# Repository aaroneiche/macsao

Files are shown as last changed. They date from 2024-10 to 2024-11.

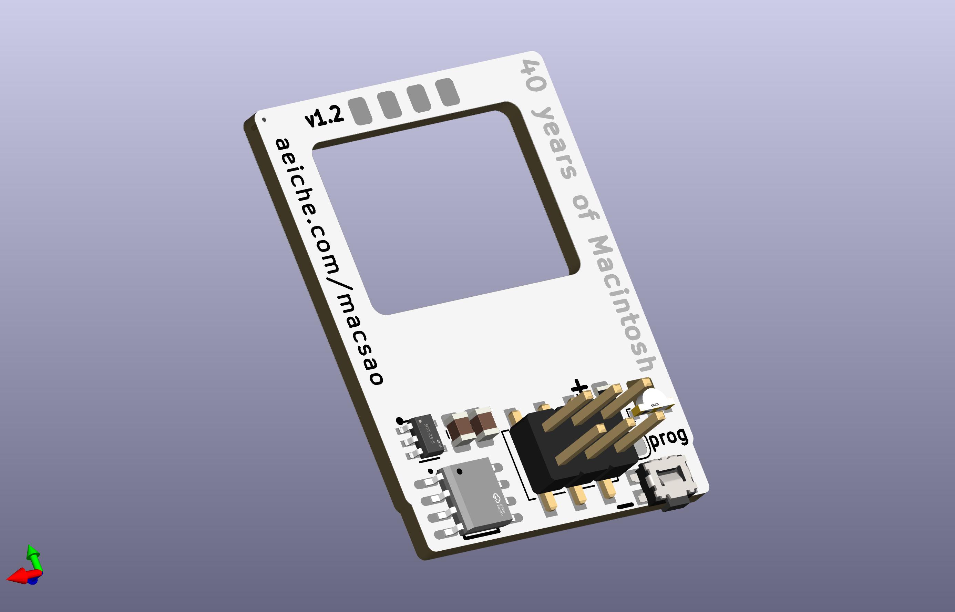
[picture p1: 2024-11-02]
other/MacSAO3D.jpg

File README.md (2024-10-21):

# Mac SAO 

The Mac SAO is a simple add-on I've built heading into Hackaday Supercon 2024. It is a celebration of the original Macintosh, which debuted 40 years ago in 1984. 

In the spirit of Open source and good faith hardware hacking, all of the code here is open to use. If you do so, I would love to know.

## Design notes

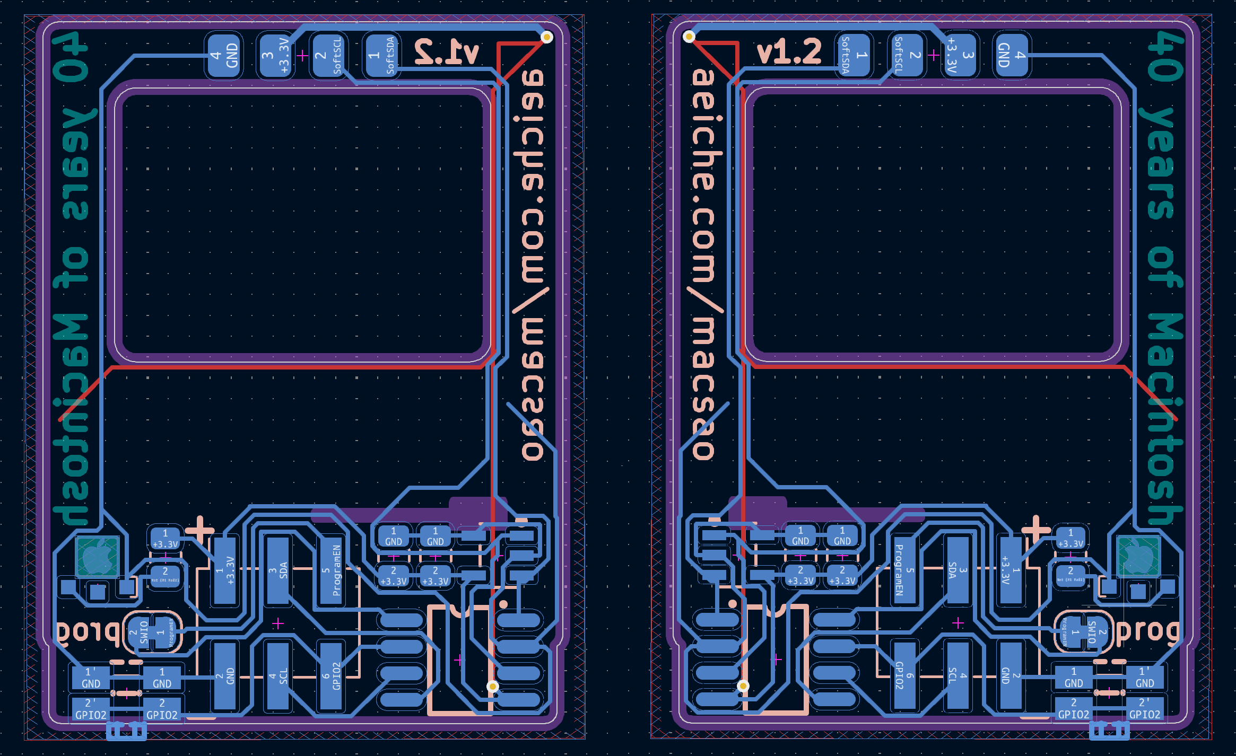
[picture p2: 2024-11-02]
other/frontAndBack.png

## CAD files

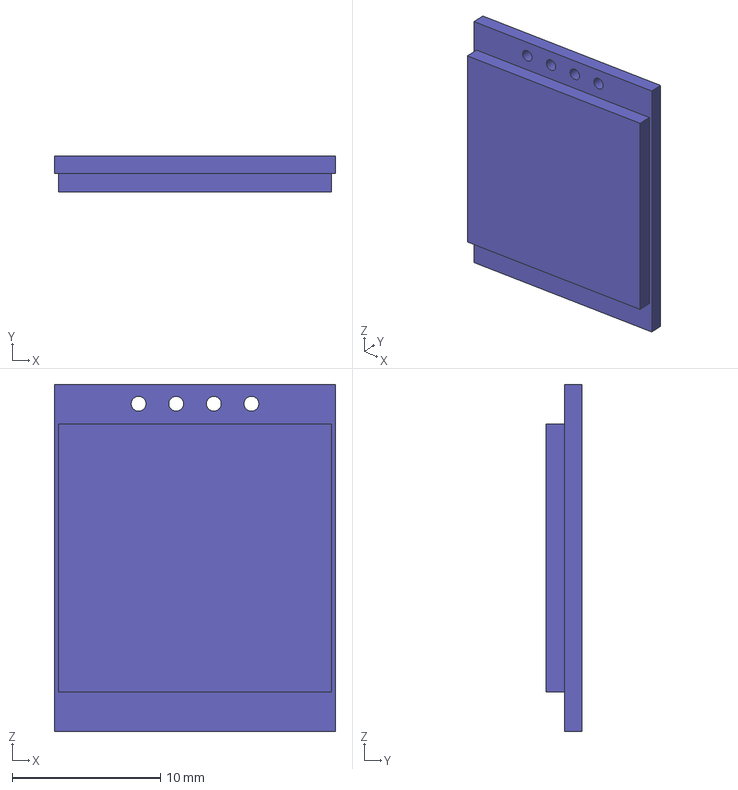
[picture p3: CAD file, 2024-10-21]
hardware/oledModule.step
19.0 x 2.45 x 23.4 mm

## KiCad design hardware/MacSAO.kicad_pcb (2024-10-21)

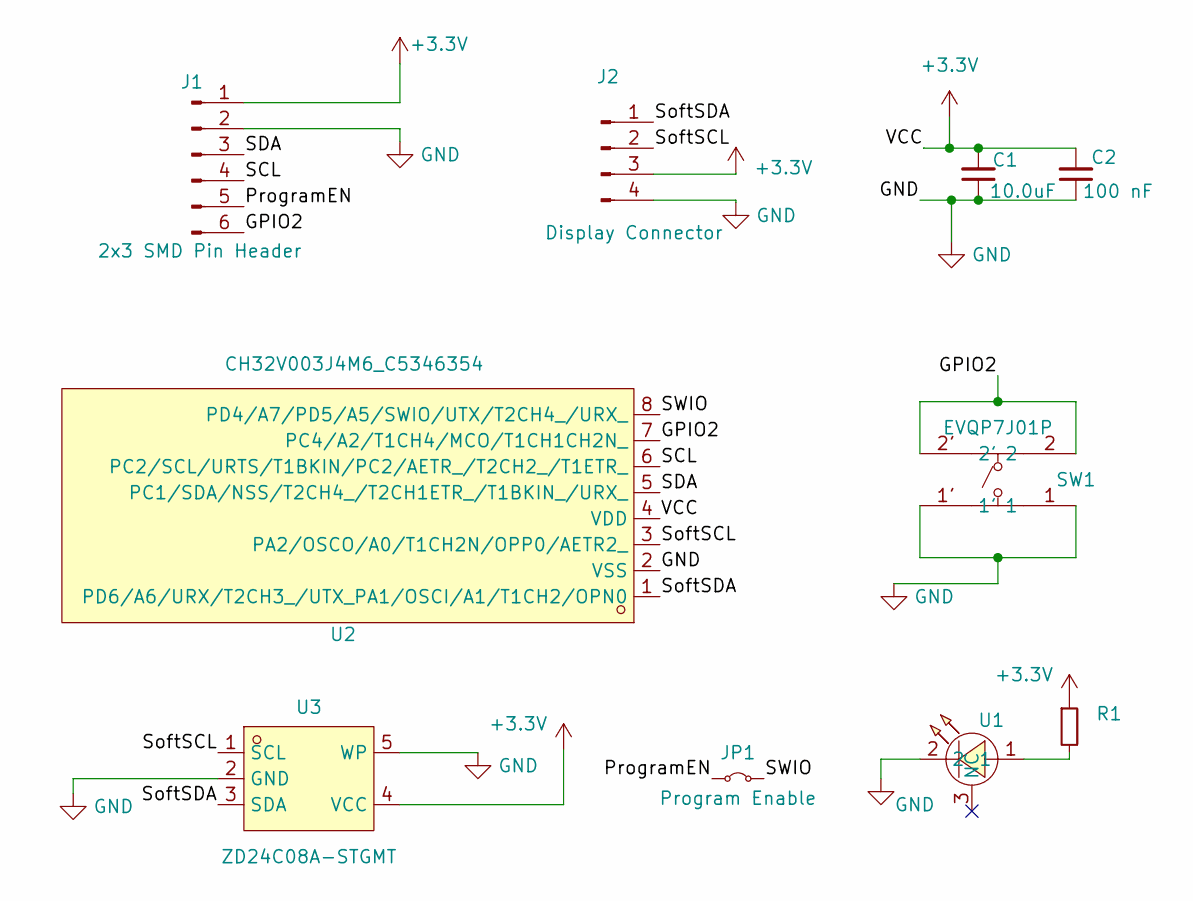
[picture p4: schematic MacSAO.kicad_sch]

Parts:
C1: 10.0uF; C_0805_2012Metric
C2: 100 nF; C_0805_2012Metric
J1: 2x3 SMD Pin Header; PinHeader_2x03_P2.54mm_Vertical_SMD
J2: Display Connector; 1x04_SMD_OLED
JP1: Program Enable; SolderJumper-2_P1.3mm_Bridged_RoundedPad1.0x1.5mm
R1: 1.8Kohm; R_0805_2012Metric
SW1: EVQP7J01P; SW-SMD_EVQP7J01P; LCSC Part C2828254
U1: A-SP110GHC-C01-2C; LED-SMD_L3.0-W1.5_MHS110WDT-C1; LCSC Part C5151480
U2: CH32V003J4M6_C5346354; SOP-8_L4.9-W3.8-P1.27-LS6.0-BL; LCSC Part C5346354
U3: ZD24C08A-STGMT; SOT-23-5_L3.0-W1.7-P0.95-LS2.8-BL; LCSC Part C2896640

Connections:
+3.3V: C1.2, C2.2, J1.1, J2.3, R1.1, U2.4 (VDD), U3.4 (VCC)
/GPIO2: J1.6, SW1.2, SW1.2', U2.7 (PC4/A2/T1CH4/MCO/T1CH1CH2N_)
/ProgramEN: J1.5, JP1.1 (A)
/SCL: J1.4, U2.6 (PC2/SCL/URTS/T1BKIN/PC2/AETR_/T2CH2_/T1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)
/SDA: J1.3, U2.5 (PC1/SDA/NSS/T2CH4_/T2CH1ETR_/T1BKIN_/UR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)
/SWIO: JP1.2 (B), U2.8 (PD4/A7/PD5/A5/SWIO/UTX/T2CH4_/URX_)
/SoftSCL: J2.2, U2.3 (PA2/OSCO/A0/T1CH2N/OPP0/AETR2_), U3.1 (SCL)
/SoftSDA: J2.1, U2.1 (PD6/A6/URX/T2CH3_/UTX_PA1/OSCI/A1/T1CH2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), U3.3 (SDA)
GND: C1.1, C2.1, J1.2, J2.4, SW1.1, SW1.1', U1.2, U2.2 (VSS), U3.2 (GND), U3.5 (WP)
unnamed: R1.2, U1.1

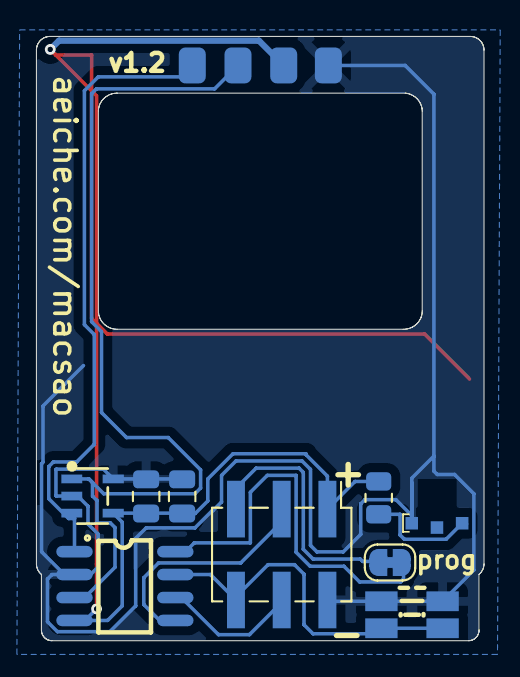
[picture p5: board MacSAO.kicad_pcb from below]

Board: 2 copper layers, 24.9 x 33.6 mm, 10 parts (10 on the bottom side), 10 nets.

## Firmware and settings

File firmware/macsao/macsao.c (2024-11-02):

/*
 * MacSAO Firmware Aaron Eiche 2024
 * 
 * Started from E. Brombaugh's OLED Demo, 
 * Utilizes ADBeta's Software I2C Library
 */

// what type of OLED - uncomment just one
#define SSD1306_64X48
// #define SSD1306_64X32
// #define SSD1306_128X32
// #define SSD1306_128X64

#ifndef _FUNCONFIG_H
#define _FUNCONFIG_H

// Though this should be on by default we can extra force it on.
#define FUNCONF_USE_DEBUGPRINTF 1
#define FUNCONF_DEBUGPRINTF_TIMEOUT (1 << 31) // Wait for a very very long time.

#define CH32V003 1

#endif

#include "ch32v003fun.h"
#include <stdio.h>
#include "ssd1306.h"
#include <string.h>

// #include "bomb.h"
#include "../extralibs/ch32v003_GPIO_branchless.h"
#include "i2c_slave.h"
#include "lib_swi2c.c"
#include "ssd1306_i2c.h"

#include "decoder.c"

// State: Either in settings mode or "Mac" animation playback.
#define MAC 0
#define SETTINGS 1

#define ANIMATE 0
#define LIVEDRIVE 1
#define SETTINGS 2



uint8_t mode = ANIMATE;
uint8_t lastMode = ANIMATE;
bool hasDrawn = false;

volatile uint32_t overflowCount = 0;

uint8_t buttonLastState = 0;
int start = 0;
int stop = -1;
bool counting = false;
bool buttonShortPress = false;

//Where i2c input goes after being received.
volatile uint8_t i2c_registers[32] = {};

//Where EEPROM data is put to make available externally.
volatile uint8_t eepData[64]; // max data to read in.

const uint8_t defaultStack[] = {
// 1,2,5,5,5,35,24,1,254,16,34,38,22,3,4,255,1,2,5,5,5,10,30,1,254,16,10,18,255,255};
1,1,254,16,58,8,255,1,3,5,5,8,35,24,2,254,22,4,6,16,58,43,16,8,11,255,255};

//Default display stack
volatile uint8_t displayStack[255] = {
	/*
	//Writes "Welcome to Supercon"

	3, 255, 16, 48, 40, 3, 255, 16, 9, 2,
	3, 255,
	20, 4, 20, 87, 101, 108, 99, 111, 109, 101, 32, 116, 111,
	115, 117, 112, 101, 114, 99, 111, 110, 254,
	3, 255,
	19, 4, 20, 87, 101, 108, 99, 111, 109, 101, 32, 116, 111,
	115, 117, 112, 101, 114, 99, 111, 110, 254,
	18, 10, 255
	 */
};

// This stack displays the settings menu. 
// The 3rd arg (10) is the selected value of the settings, 
// its updated when preferences are loaded.
volatile uint8_t settingsStack[32] = {
	1, 1, 48, 10, 254, 254, 254, 254 //, 16, 38, 40, 255, 255
};

volatile uint8_t preferences[16];

/* 
These variables keep track of the step in the sequence we're on, 
as well as the item in the sequence we're currently drawing.
 */
uint8_t * stackPtr = displayStack; // 
// uint8_t * stepPtr = displayStack; // each step in the display stack.


uint8_t * bgStartPtr = displayStack;
uint8_t * actionStartPtr;

// Keeps track of persistant info:
// Mouse X,Y, and animation step complete(0:1), wait count
uint8_t store[] = {5, 5, 0, 0};

uint16_t r_addr;
uint8_t len;

uint8_t	ssd1306_soft_init(void);

// volatile uint8_t state = MAC;
// volatile uint8_t state = SETTINGS;
bool drawn = false;

void onWrite(uint8_t reg, uint8_t length) {
	for(int c = 0; c < length; c++) {
		printf("%u: %u\n", c, i2c_registers[c]);
	}

	//Reset the state of the i2c lines, in case anything else is happening.
	swi2c_init(&device);

	switch (i2c_registers[0])
	{
		case 1: {
		//write to display data.
		
		//Clear the store data in case the new command is using it.
		store[3] = 0;

		// Get the address offset to write
		uint8_t offset = i2c_registers[1];

		for (int i = 2; i <= length; i++)
		{
			displayStack[offset + i - 2] = i2c_registers[i];
		};

		// displayStack[length-1] = 0xFF; // A final byte at the end of last animation
		
		stackPtr = displayStack;
		actionStartPtr = displayStack;
		bgStartPtr = displayStack;

		if(mode == LIVEDRIVE) {
			hasDrawn = false;
		}

		break;
		}
		case 2: 
		//write to stored memory

		// 16bit address. Here to auto-overflow. 
		uint16_t addr = (i2c_registers[1] << 8) | i2c_registers[2];
		// printf("address: %4x\n", addr);
		// Get distance to end of page.

		uint8_t bytesForPage = 32 - (addr % 32); // How far to end of page.

		uint8_t *sptr = i2c_registers + 3; //A pointer to the first byte we're gonna send.
		int8_t dataLen = length - 3; // Length of the data to store.

		// printf("data length: %u\n", dataLen);
		// printf("byte value of array: %u\n", sptr);
		while (dataLen > 0) // While there are bytes to write
		{
			// printf("another loop: %u\n", dataLen);
			// printf("addr: %u, bytesForPage %u, datalength %u\n", addr, bytesForPage, dataLen);

			if (dataLen > bytesForPage) // We have more bytes than can write in this page.
			{

				// printf("sending %u bytes to %4x\n",addr, dataLen);
				//send bytes at pointer, for bytesForPage length
				swi2c_master_transmit_eeprom(&eeprom, addr, sptr, dataLen);
				
				//reduce the number of bytes to write.
				dataLen -= bytesForPage;
				
				//increment the address pointer
				sptr +=  bytesForPage; // Array pointer
				addr += bytesForPage; // address value.

				// update bytesForPage to the next length of bytes to send.
				bytesForPage = 32 - (addr % 32);
			}
			else // We can write these bytes just to this page.
			{
				// printf("one shot: sending %u bytes to %4x\n", dataLen, addr);
				swi2c_master_transmit_eeprom(&eeprom, addr, sptr, dataLen);
				dataLen -= bytesForPage; // subtract remaining bytes.
			}
		}

		break;

		case 3: //Read Data either from display stack (FFFF) or FROM EEPROM (0000-2000)
			
			r_addr = (i2c_registers[1] << 8) | i2c_registers[2]; //16-bit address
			len = i2c_registers[3];
			
			if(r_addr == 0xFFFF) { 
				// FFFF is not a valid EEPROM address (this is only 64kbits)
				//Read display stack in, rather than 
				for(int i = 0; i < len; i++){
					eepData[i] = displayStack[i];
				}
			}else{
				swi2c_master_receive_eeprom(&eeprom, r_addr, eepData, len);
			}
						
			
			for (int i = 0; i < len; i++)
			{
				// printf("%u: %u\n", i, eepData[i]);
				i2c_registers[i] = eepData[i];
				// memcpy(i2c_registers, eepData, len); //copy the data over to i2cr
			}
			// memcpy(i2c_registers, eepData, len);
			// for (int r = 0; r < len; r++)
			// {
			// 	printf("reg %u: %u\n",r,i2c_registers[r]);
			// }
		break;
		case 4:
			// Load a sequence from EEPROM into displayStack
			// 4 Args: Address Hi, Address Low, Number of Bytes, offset on displayStack

			uint16_t r_addr = (i2c_registers[1] << 8) | i2c_registers[2]; // 16-bit address
			len = i2c_registers[3];						// Number of bytes to read

			// Where to place the new bytes in the display stack
			// useful if you want to add to existing stack.
			uint8_t stackOffset = i2c_registers[4];		
			swi2c_master_receive_eeprom(&eeprom, r_addr, eepData, len);

			// write eepData vals into displayStack
			for(int i = 0; i < len; i++) {
				displayStack[stackOffset + i] = eepData[i]; 
			}
			
			displayStack[stackOffset + len] = 255; // Extra 255 at end of new data indicates end of Sequence.

			// reset display stack
			stackPtr = displayStack;
			actionStartPtr = displayStack;
			bgStartPtr = displayStack;
		break;
		
		case 5: 
			//Set one of the variables in the Mac.
			switch (i2c_registers[1]) {
				case 1: // Animate(0) or LiveDrive(1)
					lastMode = mode;
					mode = i2c_registers[2];
					// printf("setting mode to %u", mode);
				break;
				case 2: // Mouse X,Y
					store[0] = i2c_registers[2];
					store[1] = i2c_registers[3];
					// printf("set mouse X,Y to %u,%u", store[0], store[1]);
				break;
			}

			stackPtr = displayStack;
			actionStartPtr = displayStack;
			bgStartPtr = displayStack;

			if(mode == LIVEDRIVE) {
				hasDrawn = false; // Trigger an update.
			}
			break;
		case 6:
			//Read variable value;
			switch (i2c_registers[1])
			{
			case 1: // Animate(0) or LiveDrive(1)
				i2c_registers[0] = mode;
				break;
			case 2: // Mouse X,Y
				i2c_registers[0] = store[0];
				i2c_registers[1] = store[1];
				break;
			}
		}
	printf("command finished.\n");

}

void onRead(uint8_t reg) {
	// read data out of eepData
	// SetupI2CSlave
	printf("Read %u at ...\n",i2c_registers[reg], reg);
}


/* 
	Explicitly sets the i2c address of the MacSAO
*/
void setI2CAddress(uint8_t addressVal){
	if (swi2c_start(&eeprom) == I2C_OK)
	{
		swi2c_master_tx_byte(&eeprom, eeprom.address);		  // Transmit Address w/write bit;
		swi2c_master_tx_byte(&eeprom, 0); // Address High Byte
		swi2c_master_tx_byte(&eeprom, 0);		  // Address Low Byte
		swi2c_master_tx_byte(&eeprom, addressVal); // Address Low Byte
		swi2c_stop(&eeprom);
	}
} 

void readData(uint8_t addrH, uint8_t addrL, uint8_t data[], uint8_t length)
{
	if (swi2c_start(&eeprom) == I2C_OK)
	{
		swi2c_master_tx_byte(&eeprom, eeprom.address); // Transmit Address w/write bit;
		swi2c_master_tx_byte(&eeprom, addrH);		   // Page Address High Byte
		swi2c_master_tx_byte(&eeprom, addrL);		   // Page Address Low Byte
		// swi2c_stop(&eeprom);
	}

	if (swi2c_start(&eeprom) == I2C_OK)
	{
		swi2c_master_tx_byte(&eeprom, eeprom.address | 1); // Transmit Address w/read bit;
		for (int i = 0; i < length; i++)
		{
			
			data[i] = swi2c_master_rx_byte(&eeprom, I2C_ACK); //Read bytes into data.
			// printf("read %u %u\n",i, data[i]);
		}
		swi2c_master_rx_byte(&eeprom, I2C_NACK); //End Sequential Read.
		swi2c_stop(&eeprom);
	}
}

void writeData(uint8_t addrH, uint8_t addrL,  uint8_t data[], uint8_t length ) {
	printf("writing data\n");
	if (swi2c_start(&eeprom) == I2C_OK)
	{
		// printf("i2c ok: ");
		swi2c_master_tx_byte(&eeprom, eeprom.address); 	// Transmit Address w/write bit;
		swi2c_master_tx_byte(&eeprom, addrH); 			// Address High Byte
		swi2c_master_tx_byte(&eeprom, addrL);		  	// Address Low Byte
		for(int l = 0; l < length; l++){
			swi2c_master_tx_byte(&eeprom, data[l]);
		} 
		swi2c_stop(&eeprom);
		// printf("\n\n");
	}
}

void getStored(uint16_t address, uint8_t data[], uint8_t length) {
	//Set the read address
	if(swi2c_start(&eeprom) == I2C_OK) {
		swi2c_master_tx_byte(&eeprom, eeprom.address); 			// Transmit Address w/write bit;
		swi2c_master_tx_byte(&eeprom, (address >> 8) & 0xFF);   // Address High Byte
		swi2c_master_tx_byte(&eeprom, address & 0xFF);			// Address Low Byte
		// swi2c_stop(&eeprom);
	}
	
	//Read the EEPROM
	if (swi2c_start(&eeprom) == I2C_OK)
	{
		swi2c_master_tx_byte(&eeprom, eeprom.address | 1); // Transmit Address w/read bit;
		for (int i = 0; i < length; i++)
		{
			data[i] = swi2c_master_rx_byte(&eeprom, I2C_ACK);
		}
		swi2c_master_rx_byte(&eeprom, I2C_NACK);
		swi2c_stop(&eeprom);
	}
	
}

/*  
Button press Interrupt
*/
void EXTI7_0_IRQHandler(void) __attribute__((interrupt));
void EXTI7_0_IRQHandler(void)
{
	int res = funDigitalRead(PC4);
	// Delay_Ms(10); // debounce
	// int resB = funDigitalRead(PC4);
	
	// if(res == resB) {
		//debounced, this is fine.
		if (res)
		{ //Button pulls up.
			stop = SysTick->CNT; //The end of the button press time.

			//Set counting to 
			if (counting && (stop - start) / 4799 > 50) 
			{
				buttonShortPress = true;
			}
			counting = false;
		}
		else
		{ //Button Pressed
			start = SysTick->CNT;
			counting = true;
		}
	// }

	// Acknowledge the interrupt
	EXTI->INTFR = EXTI_Line4;
}


void setMode(uint8_t newMode) {
	lastMode = mode;
	// printf("New mode is %u", newMode);
	mode = newMode;
	if(mode == SETTINGS){
		stackPtr = settingsStack;
	}else{
		stackPtr = displayStack;
	}
}


/* 
int stateManager(int newState) {
	if (newState == SETTINGS)
	{
		printf("state to SETTINGS\n");
		stackPtr = settingsStack; // each item in the display stack
		// stepPtr = settingsStack;  // each step in the display stack.

		actionStartPtr = settingsStack;
		bgStartPtr = settingsStack;
		return SETTINGS;
	}
	else if(newState == MAC)
	{
		printf("state to MAC\n");
		stackPtr = displayStack; // each item in the display stack
		// stepPtr = displayStack;	 // each step in the display stack.

		actionStartPtr = displayStack;
		bgStartPtr = displayStack;

		return MAC;
	}
	return MAC; // If somehow we don't return properly...
}
 */


int main()
{

	// 48MHz internal clock
	SystemInit();
	funGpioInitAll();

	//Setup the button input.
	funPinMode(PC4, GPIO_CFGLR_IN_PUPD); 
	funDigitalWrite(PC4, FUN_HIGH);	

	//Setup the interrupt handler for the button.
	AFIO->EXTICR = AFIO_EXTICR_EXTI4_PC;
	EXTI->INTENR = EXTI_INTENR_MR4; // Enable EXT4
	EXTI->RTENR =  EXTI_RTENR_TR4; // Rising edge trigger
	EXTI->FTENR = EXTI_FTENR_TR4;  //Falling edge trigger

	NVIC_EnableIRQ(EXTI7_0_IRQn);
/*
	RCC->APB2PCENR |= RCC_APB2Periph_TIM1; //Enable Timer1
	// RCC->APB2PRSTR |= RCC_APB2Periph_TIM1; //Reset Timer?


	//Initialize Timer 1 		
	TIM1->PSC = 4799; 		// 48Mhz = 0.1ms
	TIM1->ATRLR = 0x7530;	//Auto reload register
	
	// TIM1->INTFR &= ~TIM_UIF; //Clear the interrupt before enabling.
	// printf("--%16x\n",TIM1->INTFR);

	// TIM1->INTFR = ~TIM_UIF;
	TIM1->DMAINTENR |= TIM_UIE; //Enable the interrupt enable register.

	// printf("--%16x\n", TIM1->INTFR);
	// printf("DMA --%16x\n", TIM1->DMAINTENR);

	TIM1->CNT = 0; //Initial count to 0
	
	// TIM1->INTFR &= ~TIM_UIF; // clear interrupt flag.
	// TIM1->CTLR1 |= TIM_CEN; // Enable the counter.

	TIM1->INTFR &= ~TIM_UIF; // Clear the interrupt before enabling.

	// NVIC_EnableIRQ(TIM1_UP_IRQn); //Setup Timer 1 interrupt.
*/

	buffer_clear(1); //set the MacPaint buffer to white

	// initialize i2c for Display.
	i2c_err_t a = swi2c_init(&device);

	if (a != I2C_OK){
		// printf("Error in i2c Device Setup: %u\n", a);
	}

	//Initialize I2C as target for talking to host badge.
	funPinMode(PC1, GPIO_CFGLR_OUT_10Mhz_AF_OD); // SDA
	funPinMode(PC2, GPIO_CFGLR_OUT_10Mhz_AF_OD); // SCL

	// Get stored preferences from the EEPROM.
	getStored(0x0000, preferences, 16);

	//Default Address in case something goes wrong.
	if(preferences[0] != 10 && preferences[0] != 34 && preferences[0] != 86) {
		preferences[0] = 10;
	}
	//Make sure the display data for settings is up-to-date.
	settingsStack[3] = preferences[0];

	// Preferences 1 and 2 are address bytes (high and low) load data from.
	uint16_t loadFromAddr = (preferences[1] << 8) | preferences[2];
	printf("loadFrom address: %4x\n", loadFromAddr, preferences[1], preferences[2]);
	//Preferences 3 is the number of bytes to load.

	if(loadFromAddr != 0 && loadFromAddr != 0xFFFF ) {
		printf("Stored address is %4x. Loading...\n", loadFromAddr);
		// Get data from eeprom
		getStored(loadFromAddr, displayStack, preferences[3]);
		displayStack[preferences[3]] = 255;
		
	}else{
		printf("Stored address is 0, playing default\n");

		memcpy(displayStack, defaultStack, sizeof(defaultStack));
		
		// for(int i =0; i < sizeof(defaultStack); i++) {
		// 	printf("%u:  %u\n",i,displayStack[i]);
		// }
		// displayStack[sizeof(defaultStack)] = 255;

	} // Else display stack remains default, or current or whatever.

	// Setup I2C from the badge.
	SetupI2CSlave(preferences[0], i2c_registers, sizeof(i2c_registers), onWrite, NULL, false);
	
	//Setup display
	ssd1306_soft_init();

	// printf("Command Start: %u\n", displayStack);

	while(1) {

		if(counting == true && ((SysTick->CNT - start)/47999) > 350) {
			counting = false; // Stop counting. We're not doing anything else here
			// state = stateManager(!state);
			// mode = (mode != SETTINGS)? SETTINGS:lastMode;
			setMode((mode != SETTINGS) ? SETTINGS : lastMode);
			hasDrawn = false;
		} 
		// printf("post button check. State now: %u\n",state);
		if(buttonShortPress) {
			if(mode == SETTINGS){
				//advance I2C Address
				switch(preferences[0]) {
					case 10:
						preferences[0] = 34;
					break;
					case 34:
						preferences[0] = 86;
					break;
					case 86:
						preferences[0] = 10;
					break;
				}
				settingsStack[3] = preferences[0];
				setI2CAddress(preferences[0]);
				stackPtr = settingsStack;
				// printf("stack pointer again at\n: %u",stackPtr);
			}
			printf("button short!\n");

			hasDrawn = false;
			//Here is where button handling is for advancing the state
			buttonShortPress = false;
		}

		/* 
			Typical command: 

			2 7				MacPaint Tool #7
			254				END background
			16 40 40 		MouseTo (40,40)
			18 10			Wait 1 second (10 * 100ms)
			255				End of Action, move to next background.
			
			Abstraction: 

			//If in Background mode: 
			Run through all commands until you hit a 254.
			Switch to Action mode
			Step Forward one
			
			If current ActionStartPtr is greater than this, step forward (repeat until you get to current)
			If current ActionStartPtr is less than this, set this command to ActionStartPtr 
			
			Run through commands (some may issue repeat) 
				return 0 means go back to backgroundPtr
				return 1 means move ahead to next command
			
			...Until you get to 255
			
			Step Forward one
			Set Background Ptr to this command
		*/



		if(mode == ANIMATE) {
		//---

			while (*stackPtr != 254)  // Not 254. In background
			{
				// printf("current bg: %u \n",*stackPtr);
				decoder(&stackPtr, store); // Decode command, include store for data access/updates.
				stackPtr++;
			}
			// printf("Stack is 254\n");
			stackPtr++; 	//Advance to the first item in the Action set

			// printf("StackPtr: %u, ActionStartPtr: %u\n", stackPtr, actionStartPtr);

			//check if this is the current Action 
			while(stackPtr < actionStartPtr) {
				// printf("skip: %u \n", *stackPtr);
				stackPtr++;	//increment the stack pointer until we're at the right action.
			}
			// printf("current action: %u \n", *stackPtr);
			//Now we're at the right action
			decoder(&stackPtr, store);

			//if this action completed, advance the stackptr
			if (store[2] == 1) {
				stackPtr++;
				actionStartPtr = stackPtr;
				store[2] = 0; //clear after processed.
			}else{
				//Done - draw and go back to background to repeat.
				stackPtr = bgStartPtr;
			}

			// printf("displaying...\n");
			ssd1306_refresh(); // Update the display.

			if(*stackPtr == 255) {
				// printf("end of action\n");
				//end of actions for this background. Set background to next address.
				// printf("ptr before: %u\n", *stackPtr);
				stackPtr++;

				// printf("ptr now: %u at %u\n", *stackPtr, stackPtr);

				// if *this* address is also 255, that's the end of commands, go back to the beginning.
				if(*stackPtr == 255) {
					// printf("double 255, end of command set. Starting over\n");
					stackPtr = displayStack;
					actionStartPtr = displayStack; //Since we don't know where the first action is, it'll always be behind the stack pointer
					bgStartPtr = stackPtr;

					// if (mode != SETTINGS)
					// {
					// 	// printf("Mac!\n");
					// 	stackPtr = displayStack;
					// 	actionStartPtr = displayStack;
					// 	bgStartPtr = stackPtr;
					// 	// printf("%u\n",stackPtr);
					// }
					// else if (mode == SETTINGS)
					// {
					// 	stackPtr = settingsStack;
					// 	actionStartPtr = settingsStack;
					// 	bgStartPtr = stackPtr;
					// }
				}else{
					bgStartPtr = stackPtr;
				}
			}else{
				stackPtr = bgStartPtr;
			}
		}else if(mode == LIVEDRIVE){
			if(!hasDrawn) {
				// draw whatever is in the background
				while (*stackPtr != 254) // Not 254. In background
				{
					// printf("current bg: %u \n",*stackPtr);
					decoder(&stackPtr, store); // Decode command, include store for data access/updates.
					stackPtr++;
				}

				// Draw the mouse?
				ssd1306_drawImage(store[0], store[1], pointerOutline, 8, 8, 4);
				ssd1306_drawImage(store[0] + 1, store[1], pointer, 8, 8, 5);

				// Write character buffer? -- for MacWrite
			

				ssd1306_refresh(); // Update the display.
				// Mark the draw as complete, so it doesn't draw anymore.
				hasDrawn = true;
				stackPtr = displayStack; // reset the stack pointer
			}
		}else if(mode == SETTINGS) {
			
			
			if(!hasDrawn) {
				
				stackPtr = settingsStack;
				// printf("stack pointer now pointing at %u\n",stackPtr);
				while (*stackPtr != 254) // Not 254. In background
				{
					// printf("current bg: %u \n",*stackPtr);
					decoder(&stackPtr, store); // Decode command, include store for data access/updates.
					stackPtr++;
				}
				ssd1306_refresh(); // Update the display.
				hasDrawn = true;
			}
			
		}

	}
}


uint8_t ssd1306_soft_init(void)
{
	// initialize OLED
	uint8_t *cmd_list = (uint8_t *)ssd1306_init_array;
	while (*cmd_list != SSD1306_TERMINATE_CMDS)
	{
		ssd1306_cmd(*cmd_list++);
	}
	// clear display
	ssd1306_setbuf(0);
	ssd1306_refresh();

	return 0;
}

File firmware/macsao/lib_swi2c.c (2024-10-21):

/******************************************************************************
* lib_GPIOCTRL
* A runtime-capable GPIO Library, with Digital Read/Write and
* TODO: Analog Read & Analog Write/PWM
*
*
* See GitHub for details: https://github.com/ADBeta/CH32V003_lib_GPIOCTRL
*
* ADBeta (c) 2024
******************************************************************************/
#include "lib_swi2c.h"

#include <stdint.h>
#include <stdbool.h>
#include <stdio.h>

/*** Copied from lib_GPIOCTRL ************************************************/
// https://github.com/ADBeta/CH32V003_lib_GPIOCTRL

/*** GPIO Pin Mode Enumeration ***********************************************/
/// @breif GPIO Pin Mode data. The lower nibble is the raw binary data for the
/// [R32_GPIOx_CFGLR] Register. The upper nibble is used for additional flags 
typedef enum {
	INPUT_ANALOG       = 0x00,
	INPUT_FLOATING     = 0x04,
	INPUT_PUSHPULL     = 0x08,
	// NOTE: Removed to simplify code (speed)
	// Mapped to INPUT_PP, Sets OUTDR based on the upper nibble
	// INPUT_PULLUP       = 0x18,
	// INPUT_PULLDOWN     = 0x08,
	//
	OUTPUT_10MHZ_PP    = 0x01,
	OUTPUT_10MHZ_OD    = 0x05,
	//
	OUTPUT_2MHZ_PP     = 0x02,
	OUTPUT_2MHZ_OD     = 0x06,
} gpio_mode_t;


/*** GPIO Output State Enumerations ******************************************/
/// @breif GPIO Pin State Enum, simple implimentation of a HIGH/LOW System
typedef enum {
	GPIO_LOW     = 0x00,
	GPIO_HIGH    = 0x01,
} gpio_state_t;


/*** Registers for GPIO Port *************************************************/
/// @breif GPIO Port Register, Directly Maps to Memory starting at 
/// [R32_GPIOx_CFGLR] for each PORT Respectively
typedef struct {
	volatile uint32_t CFGLR;  // Configuration Register (lower)
	volatile uint32_t CFGHR;  // Configuration Register (upper)
	volatile uint32_t INDR;   // Input Data Register
	volatile uint32_t OUTDR;  // Output Data Register
	volatile uint32_t BSHR;   // Set/Reset Register
	volatile uint32_t BCR;    // Port Reset Register
	volatile uint32_t LCKR;   // Lock Register
} gpio_port_reg_t;


/*** Register Address Definitions ********************************************/
#define RCC_APB2PCENR ((volatile uint32_t *)0x40021018)
#define APB2PCENR_AFIO   0x01
#define APB2PCENR_IOPxEN 0x04

#define PORTA_GPIO_REGISTER_BASE 0x40010800
// NOTE: PORTB is not available for the CH32V003.
#define PORTB_GPIO_REGISTER_BASE 0x40010C00
#define PORTC_GPIO_REGISTER_BASE 0x40011000
#define PORTD_GPIO_REGISTER_BASE 0x40011400

#define GPIO_PORTA ((gpio_port_reg_t *)PORTA_GPIO_REGISTER_BASE)
// NOTE: PORTB is not available for the CH32V003.
#define GPIO_PORTB ((gpio_port_reg_t *)PORTB_GPIO_REGISTER_BASE)
#define GPIO_PORTC ((gpio_port_reg_t *)PORTC_GPIO_REGISTER_BASE)
#define GPIO_PORTD ((gpio_port_reg_t *)PORTD_GPIO_REGISTER_BASE)

/// @breif The GPIO Ports are places into an array for easy indexing in the
/// GPIO Functions
/// NOTE: Only 3 PORTs are usable in the CH32V003, 4 for other MCUs
static gpio_port_reg_t *gpio_port_reg[4] = {
	GPIO_PORTA,
	NULL,
	GPIO_PORTC,
	GPIO_PORTD,
};

/// @breif Sets the OUTDR Register for the passed Pin
/// @param gpio_pin_t pin, the GPIO Pin & Port Variable (e.g GPIO_PD6)
/// @param gpio_state_t state, GPIO State to be set (e.g GPIO_HIGH)
/// @return None
__attribute__((always_inline))
static inline void gpio_digital_write(const gpio_pin_t pin, const gpio_state_t state)
{
	// Make array of uint8_t from [pin] enum. See definition for details
	uint8_t *byte = (uint8_t *)&pin;

	uint32_t mask = 0x01 << byte[1];          // Shift by pin number
	if(state == GPIO_LOW) mask = mask << 16;  // Shift by 16 if LOW, to Reset

	gpio_port_reg[ byte[0] ]->BSHR = mask;
}

/// @breif Reads the INDR Register of the specified pin and returns state
/// @param gpio_pin_t pin, the GPIO Pin & Port Variable (e.g GPIO_PD6)
/// @return gpio_state_t, the current state of the pin, (e.g GPIO_HIGH)
__attribute__((always_inline))
static inline gpio_state_t gpio_digital_read(const gpio_pin_t pin)
{
	// Make array of uint8_t from [pin] enum. See definition for details
	uint8_t *byte = (uint8_t *)&pin;

	// If the Input Reg has the wanted bit set, return HIGH
	if( (gpio_port_reg[ byte[0] ]->INDR & (0x01 << byte[1])) != 0x00 ) 
		return GPIO_HIGH;

	// else return LOW 
	return GPIO_LOW;
}

/// NOTE: Modified to be slimmer and lightweight. No INPUT_PULLUP/PULLDOWN, and
/// RCC Register setting is now in its own function to improve speed here.
/// @breif Sets the Config and other needed Registers for a passed pin and mode
/// @param gpio_pin_t pin, the GPIO Pin & Port Variable (e.g GPIO_PD6)
/// @param gpio_mode_t mode, the GPIO Mode Variable (e.g OUTPUT_10MHZ_PP)
/// @return None
__attribute__((always_inline))
static inline void gpio_set_mode(const gpio_pin_t pin, const gpio_mode_t mode)
{
	// Make array of uint8_t from [pin] enum. See definition for details
	uint8_t *byte = (uint8_t *)&pin;

	// Clear then set the GPIO Config Register
	//gpio_port_reg[ byte[0] ]->CFGLR &=        ~(0x0F  << (4 * byte[1]));
	//gpio_port_reg[ byte[0] ]->CFGLR |=           mode << (4 * byte[1]);
	gpio_port_reg[byte[0]]->CFGLR = 
		(gpio_port_reg[byte[0]]->CFGLR & ~(0x0F << (4 * byte[1]))) 
		| (mode << (4 * byte[1]));
}

/// @breif Sets the RCC Register for the passed pin ONLY
/// @param gpio_pin_t pin, the GPIO Pin & Port Variable (e.g GPIO_PD6)
/// @return None
__attribute__((always_inline))
static inline void gpio_set_rcc(const gpio_pin_t pin)
{
	// Make array of uint8_t from [pin] enum. See definition for details
	uint8_t *byte = (uint8_t *)&pin;
	
	// Set the RCC Register to enable clock on the specified port
	*RCC_APB2PCENR |= (APB2PCENR_AFIO | (APB2PCENR_IOPxEN << byte[0]));
}


/*** Software I2C Functions **************************************************/
// Asserting I2C lines is when they are OUTPUT Pulling LOW
#define ASSERT_SCL gpio_set_mode(i2c->pin_scl, OUTPUT_10MHZ_PP)
#define ASSERT_SDA gpio_set_mode(i2c->pin_sda, OUTPUT_10MHZ_PP)

// Releasing I2C lines is setting them INPUT FLOATING, Pulled HIGH Externally
#define RELEASE_SCL gpio_set_mode(i2c->pin_scl, INPUT_FLOATING)
#define RELEASE_SDA gpio_set_mode(i2c->pin_sda, INPUT_FLOATING)

/*** Helper Functions ********************************************************/
// Waits for the calculated amount of time (Limits bus speed)
// TODO:
__attribute__((always_inline)) static inline void wait() //Wait
{
	
}

static i2c_err_t clk_stretch(const gpio_pin_t scl)
{
	int clock_waits = 10;
	while(gpio_digital_read(scl) == GPIO_LOW)
	{
		if(!clock_waits--) return I2C_ERR_TIMEOUT;
		wait();
	}

	return I2C_OK;
}
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

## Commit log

2024-10-21 Moves ssd1306 i2c into main Fixes menu selection in mouseToMenu
    [macsao.c]
2024-10-21 Add KiCAD and PCB files
    [MacSAO-B_Cu.gbr, MacSAO-B_Mask.gbr, MacSAO-B_Paste.gbr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]
2024-10-27 - Switch decoder commands to decimal - Fixes direct-to-display write - Adds disk icon states arg to desktop - Adds masked disk Icons to tiles -Adds Icon States Tile for bitmap editor
    [macsao.c]
2024-10-30 Fix EEPROM page boundary write.
    [macsao.c]
2024-10-31 Adds Variable read control byte
    Changes Display write to require offset value.
    Display write no longer appends 255 to end of display.
    Display Stack is now 255 bytes long.
    [macsao.c]
2024-11-02 Fixes window command to include scrollbars Adds "default" animation Fixes background not drawing in LiveDrive when updated
    [macsao.c]
2026-07-31 Moves the board origin. Updates some locked items
